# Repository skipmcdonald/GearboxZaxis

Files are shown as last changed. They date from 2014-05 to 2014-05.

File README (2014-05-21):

This is a test project for a mechanical z-axis for the Shapoko 2 to move the motor out of the way and provide better clearance for large spindles such as the Dewalt 611.

The power of OpenScad is shown in the easy to understand source files.

It uses herringbone gears to reduce/eliminate backlash caused by traditional gear meshing tolerances 

The idler gear is intended to have 2 sandwiched 608 bearings and an 8mm hub.  5/16 works in a pinch.   

The lead screw gear is intended to be used with the stock Shapeoko flanged bearing that came in the kit.  Optionally a second bearing (standard 608) can sandwich the gear and held down with to top_br_zplate to add stability.

The gears are designed to be printed on a well-tuned 3d printer. 
The plates are designed to be machined out of aluminum using the Shapeoko 2.
They will be printed for a fitting prototype to ensure all dimensions and tolerances.
The zplate will be machined first. 
The other plates may remain plastic since they don't need to be that strong.

Parts List.
Basic plate hardware:
1 ZPLATE (make using dxf export from makerslide_plate.scad)
1 BR_ZPLATE ( make using dxf or stl export from makerslide_plate.scad )
2 M3 x 15mm  (retention plate fasteners)
2 M3 Nyloc Nuts
4 M3 washers
1 608 flanged bearing (from Shapeoko 2 kit)
1 M8 lead screw (from kit or longer to give additional down travel if needed)
2 M8 washers (get extras to use as optional spacers on lead screw)
3 M8 Nuts (1 below bearing 1 on top and one inserted into lead screw gear.

Stepper Motor hardware:
1 - Nema 17 stepper motor ( from kit)
2 M3 x 10mm (Nema17 z-motor mount)
2 M3 washers (optional)
1 gear (Nema17_motor_gear from gearbox.scad)
1 M3 hex nut (inserted into slot on gear)
1 M3 grub screw (secured through the gear and nut into the motor shaft flat

Gearbox
1 IDLER_GEAR (stl from gearbox.scad)
2 608ZZ sealed Skateboard bearings
1 M8 x 30mm bolt (37mm threaded rod and another nut could work instead)
1 M8 nut
1 M8 Nyloc nut
1 M8 Washer (spacer - can use extras for addition spacing as needed)

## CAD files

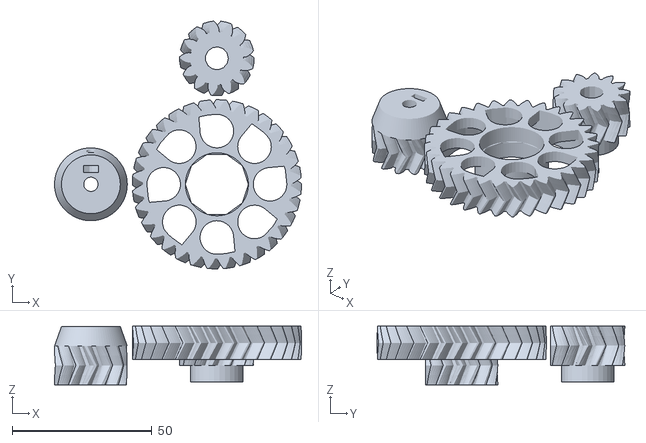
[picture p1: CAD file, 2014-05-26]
gearbox.stl
88.2 x 88.5 x 21.0

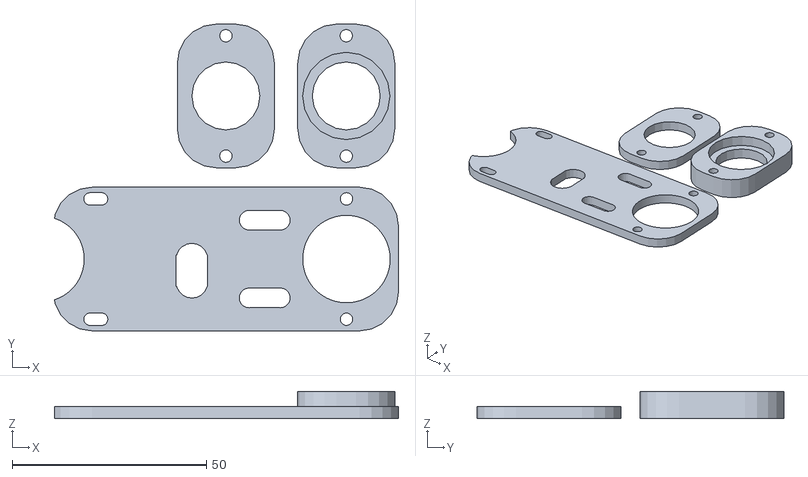
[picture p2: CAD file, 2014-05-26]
makerslide_plate.stl
88.6 x 79.0 x 7.00

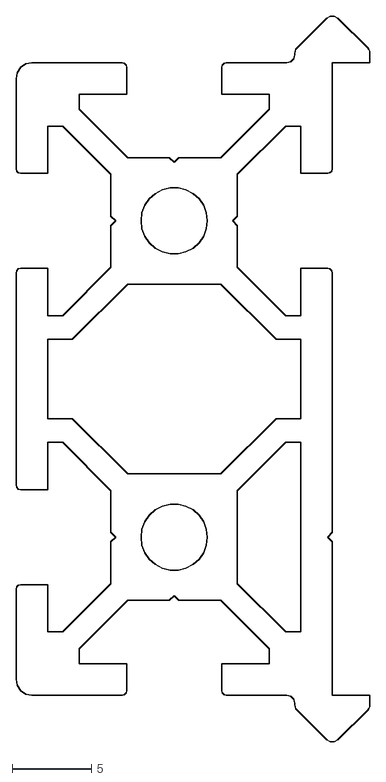
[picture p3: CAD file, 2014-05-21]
makerslide_extrusion_profile.dxf
22.4 x 45.9

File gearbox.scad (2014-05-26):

/* Gear set for Shapeoko to invert the z-axis motor and provied more clearance
 * This use 2 modules from the MCAD library that you can
 *  get from https://github.com/elmom/MCAD.
 * 
 *
 * Based roughly on extruder gear set for TechZone Huxley Copyright (C) 2011 by
 *  Guy 'DeuxVis' P. (thanks DeuxVis) which is derrived from
 *  http://www.thingiverse.com/thing:3104
 *  (thanks GilesBathgate) which is under GPL CC license.
 *
 * This program is free software; you can redistribute it and/or
 * modify it under the terms of the GNU General Public License
 * as published by the Free Software Foundation; either version 2
 * of the License, or (at your option) any later version.
 * 
 * This program is distributed in the hope that it will be useful,
 * but WITHOUT ANY WARRANTY; without even the implied warranty of
 * MERCHANTABILITY or FITNESS FOR A PARTICULAR PURPOSE.  See the
 * GNU General Public License for more details.

 * You should have received a copy of the GNU General Public License
 * along with this program; if not, write to the Free Software Foundation, 
 * Inc., 51 Franklin Street, Fifth Floor, Boston, MA  02110-1301, USA.
 */ 
 // Go to the bottom of this file and remove selected comments to get parts you can print.
// flip stl exported part over before printing and print each part separately for best results.

include <MCAD/teardrop.scad>
include <MCAD/involute_gears.scad>

/* Herringbone gear module, adapted from MCAD/involute_gears */
module herringbone_gear( teeth=12, circles=0, shaft=5, height=14 ) {
  twist=200;
//  height=14;
  pressure_angle=30;

  gear(
    number_of_teeth=teeth,
    circular_pitch=320,
		pressure_angle=pressure_angle,
		clearance = 0.2,
		gear_thickness = height/2,
		rim_thickness = height/2,
		rim_width = 1,
		hub_thickness = height/2,
		hub_diameter=1,
		bore_diameter=shaft,
		circles=circles,
		twist=twist/teeth
  );

	mirror( [0,0,1] )
	  gear(
      number_of_teeth=teeth,
		  circular_pitch=320,
		  pressure_angle=pressure_angle,
		  clearance = 0.2,
		  gear_thickness = height/2,
		  rim_thickness = height/2,
		  rim_width = 1,
		  hub_thickness = height/2,
		  hub_diameter=1,
		  bore_diameter=shaft,
		  circles=circles,
		  twist=twist/teeth
    );
}
// Idler Gear
module idler_gear(){
tears = 8; 
  union() {
    //gear
    herringbone_gear( teeth=32, circles=0, shaft=25*2, height=12 );
	 translate([0,0,12/2-4/2]) difference() {
				cylinder(r=25.1, h=4,center = true);
				cylinder(r=22.5/2, h=4.1,center = true, $fn = 100);

		//teardrop shaped holes 
  				for(i=[0:tears-1])
   				 rotate( [0, 0, i*360/tears] )
    				  translate( [19, 0, 0] )
    				    rotate( [0, 90, 50] ) teardrop( 6, 11, 90 );

				}
	difference(){
	 translate([0,0,0]) cylinder(r=(22.5+3)/2, h=12,center = true, $fn = 100);
    translate([0,0,0]) cylinder(r=22.5/2, h=12.1,center = true,$fn = 100);
	 }
    //608 bearing trap
    difference() {
      translate( [0, 0, 0] ) cylinder( r=12, h=.5, center = true );
      translate( [0, 0, 0] ) cylinder( r=11.25, h=10, $fn=10, center = true );
    	}
    }
// shaft position
% cylinder (r=4, h = 60, center = true);
// bearing positions
% translate([0,0,-3.7])cylinder (r=22/2, h = 7, center = true);
% translate([0,0, 3.7])cylinder (r=22/2, h = 7, center = true);
// Nut clearance
% translate( [0, 0, -14] ) cylinder( r=6.6, h=7, $fn=6 );
% translate( [0, 0, -30] ) cylinder( r=6.6, h=7, $fn=6 );
// radius mesh
% cylinder (r=28.44444, h=1);

}

// Leadscrew Gear
module leadscrew_gear(){
difference() {
  union() {
    //gear
    herringbone_gear( teeth=13, circles=0, shaft=8.2 );

    //M8 bolt head fit washer
    difference() {
      translate( [0, 0, -13] ) cylinder( r=9.4, h=6 );
      translate( [0, 0, -13.5] ) cylinder( r=7.7, h=7, $fn=6 );
    }
  }
}
// shaft position
% cylinder (r=4, h = 60, center = true);
// radius mesh
% cylinder (r=11.5556, h=1);
// Nut clearance
% translate( [0, 0, -14] ) cylinder( r=6.6, h=7, $fn=6 );
% translate( [0, 0, 7] ) cylinder( r=6.6, h=7, $fn=6 );
}
 
// Motor gear
module Nema17_motor_gear(){
 union() difference() {	 
  union() {

    //gear
    herringbone_gear( teeth=13 );

    translate( [0, 0, 13.9] ) mirror( [0, 0, 1] ) difference() {
      union() {

        //base
			cylinder(h=7, r1=10.5, r2=13.0, $fn = 80);


        //shaft
 //%       cylinder( r=5, h=18 );
      }

      //captive nut and grub holes
      translate( [0, 20, 4] ) rotate( [90, 0, 0] ) union() {
        //enterance
        translate( [0, -3, 14.5] ) cube( [5.4, 6, 2.4], center=true );
        //nut
        translate( [0, 0, 13.3] ) rotate( [0, 0, 30] ) cylinder( r=3.14, h=2.4, $fn=6 );
        //grub hole
        translate( [0, 0, 5] ) cylinder( r=1.6, h=15 );
      }
    }
  }

  //shaft hole
  translate( [0, 0, 0] ) cylinder( r=2.55, h=35, center = true );
 }
// Nema 17 specs
	case = 42.3;
	holes17=31;
	collar_d = 22.05;
	collar_h = 2;
	shaft_l = 24;
	shaft_d = 5.3;
	m3 = 3.1;
	$fn = 30;
// show nema17 outline for positioning
	% cylinder (r=shaft_d/2, h=shaft_l);
	% translate([0,0, 24]) cylinder(r = collar_d/2, h = collar_h);
	% translate([holes17/2,holes17/2, 22])cylinder(r=m3/2, h = 9);
	% translate([-holes17/2,holes17/2, 22])cylinder(r=m3/2, h = 9);
	% translate([holes17/2,-holes17/2, 22])cylinder(r=m3/2, h = 9);
	% translate([-holes17/2,-holes17/2, 22])cylinder(r=m3/2, h = 9);
   % translate([0,0, 26]) cube([case,case,1], center = true);
// radius mesh
% cylinder (r=11.5556, h=1);
}

// Assembly  -maximum separation center to center of 80
module gearbox(){
rotate([0,180,0])translate( [0, 0, 0] )idler_gear();
translate( [40, 0, 0] )leadscrew_gear();
translate( [-40, 0, 0] ) Nema17_motor_gear();
}

//gearbox();  // for test fit only do not export
idler_gear();  // for stl export
translate( [0, 45, -1] ) leadscrew_gear(); // for stl export
translate( [-45, 0, -8] )Nema17_motor_gear(); // for stl export

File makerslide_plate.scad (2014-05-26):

// flip it over for viewing in the correct orientation.
// Skip McDonald copyright 2014 - GNU license use it and abuse it but give me some credit.
// Warning this desing is somewhat incomplete as of 21May2014 you have been warned.



include <gearbox.scad>

//new plate dimensions
in = 25.4;
cx = 3.5*in;
//cy = 1.5*in;
cy =37;
cz = 1/8*in;
screw3 = 3.2;
screw5 = 5.1;
screw8 = 8.1;
leadscrew = 8.5;
bearing_d = 22.50;
bearing_h = 7;
//original plate dimensions
ox = 57.15;
oy = 50.80;
oz = 6.35;
screw = 5;
rad = 10; //corner radius size

module makerslide(h=100) {
	linear_extrude(file="makerslide_extrusion_profile.dxf", layer="makerslide",height=h, center=true, convexity=10);
}

% translate([0,0,50+cz/2])makerslide();
$fn=20;
//Clearance for screw head and washer
% translate([10,10,0])cylinder(h=12, r=5/2, center = true);
% translate([10,-10,0])cylinder(h=12, r=5/2, center = true);

module zplate(){   // alumium underplate for strength -- pla for fitting prototype only
// center marker
% cylinder(h=30, r=.5); // just a guide mark doesn't effect part

// Plate Base
	difference(){
	cube([cx,cy,cz], center = true);
// Makerslide holes

	translate([6,10,0])cylinder(h=20, r=screw5/2, center = true);
	translate([6,-10,0])cylinder(h=20, r=screw5/2, center = true);
	translate([14,10,0])cylinder(h=20, r=screw5/2, center = true);
	translate([14,-10,0])cylinder(h=20, r=screw5/2, center = true);
	translate([10,-10,0])cube([8,screw,20],center = true);
	translate([10,10,0])cube([8,screw,20],center = true);
// idler gear 
// hole 0.25mm too close to leadscrew gear on purpose in
// case of gear print tolerance, length of hole allows proper tensioning
	translate([-8.75,0,0])cylinder(h=20, r=screw8/2, center = true);
	translate([-8.75,-6,0])cylinder(h=20, r=screw8/2, center = true);
	translate([-8.75,-3,0])cube([screw8,screw8,20],center = true);
// Nema17 holes
	translate([-47.5,0,0])cylinder(h=20, r=22/2, center = true, $fn = 100);
	translate([-47.5+15.5,-15.5,0])cylinder(h=20, r=screw3/2, center = true);
	translate([-47.5+15.5,15.5,0])cylinder(h=20, r=screw3/2, center = true);
	translate([-49+15.5,-15.5,0])cube([3,screw3,20], center = true);
	translate([-49+15.5,15.5,0])cube([3,screw3,20], center = true);
	translate([-50.5+15.5,-15.5,0])cylinder(h=20, r=screw3/2, center = true);
	translate([-50.5+15.5,15.5,0])cylinder(h=20, r=screw3/2, center = true);





// radius the corners
	difference(){
		translate([(cx-rad)/2,(cy-rad)/2,0]) cube([rad,rad,20],center = true);		
		translate([cx/2-rad,(cy)/2-rad,0]) cylinder(h=20, r=rad, center = true);
		}
	difference(){
		translate([(-cx+rad)/2,(cy-rad)/2,0]) cube([rad,rad,20],center = true);		
		translate([-cx/2+rad,(cy)/2-rad,0]) cylinder(h=20, r=rad, center = true);
		}
	difference(){
		translate([(-cx+rad)/2,(-cy+rad)/2,0]) cube([rad,rad,20],center = true);	
		translate([-cx/2+rad,(-cy)/2+rad,0]) cylinder(h=20, r=rad, center = true);
		}
	difference(){
		translate([(cx-rad)/2,(-cy+rad)/2,0]) cube([rad,rad,20],center = true);		
		translate([cx/2-rad,(-cy)/2+rad,0]) cylinder(h=20, r=rad, center = true);
		}

// Bearing hole
  translate([31.05,0,0])cylinder(h=15,r=bearing_d/2, center = true,$fn=100);

// Bearing retention holes
	translate([31.05,-15.5,0])cylinder(h=15,r=screw3/2, center = true);
	translate([31.05,15.5,0])cylinder(h=15,r=screw3/2, center = true);

	}

}
bx = 25;
module br_zplate(){   // bearing retention plate
// center marker
% cylinder(h=30, r=.5); // just a guide mark doesn't effect part

// Plate Base
	difference(){
		cube([bx,cy,cz], center = true);
// radius corners
	difference(){
		translate([(bx-rad)/2,(cy-rad)/2,0]) cube([rad,rad,20],center = true);		
		translate([bx/2-rad,(cy)/2-rad,0]) cylinder(h=20, r=rad, center = true);
		}
	difference(){
		translate([(-bx+rad)/2,(cy-rad)/2,0]) cube([rad,rad,20],center = true);		
		translate([-bx/2+rad,(cy)/2-rad,0]) cylinder(h=20, r=rad, center = true);
		}
	difference(){
		translate([(-bx+rad)/2,(-cy+rad)/2,0]) cube([rad,rad,20],center = true);	
		translate([-bx/2+rad,(-cy)/2+rad,0]) cylinder(h=20, r=rad, center = true);
		}
	difference(){
		translate([(bx-rad)/2,(-cy+rad)/2,0]) cube([rad,rad,20],center = true);		
		translate([bx/2-rad,(-cy)/2+rad,0]) cylinder(h=20, r=rad, center = true);
		}
// zplate mating holes
	translate([0,-15.5,0])cylinder(h=15,r=screw3/2, center = true);
	translate([0,15.5,0])cylinder(h=15,r=screw3/2, center = true);

// bearing access hole
	cylinder(h=15,r=(bearing_d-5)/2, center = true);
	}
}

bz = 7;
module br_top_zplate(){   // optional top bearing -- retention plate
// center marker -- reminds me where center is if I rotate the part
% cylinder(h=30, r=.5); // just a guide mark doesn't effect part

// Plate Base
	difference(){
		cube([bx,cy,bz], center = true);
// radius corners
	difference(){
		translate([(bx-rad)/2,(cy-rad)/2,0]) cube([rad,rad,20],center = true);		
		translate([bx/2-rad,(cy)/2-rad,0]) cylinder(h=20, r=rad, center = true);
		}
	difference(){
		translate([(-bx+rad)/2,(cy-rad)/2,0]) cube([rad,rad,20],center = true);		
		translate([-bx/2+rad,(cy)/2-rad,0]) cylinder(h=20, r=rad, center = true);
		}
	difference(){
		translate([(-bx+rad)/2,(-cy+rad)/2,0]) cube([rad,rad,20],center = true);	
		translate([-bx/2+rad,(-cy)/2+rad,0]) cylinder(h=20, r=rad, center = true);
		}
	difference(){
		translate([(bx-rad)/2,(-cy+rad)/2,0]) cube([rad,rad,20],center = true);		
		translate([bx/2-rad,(-cy)/2+rad,0]) cylinder(h=20, r=rad, center = true);
		}
// zplate mating holes
	translate([0,-15.5,0])cylinder(h=15,r=screw3/2, center = true);
	translate([0,15.5,0])cylinder(h=15,r=screw3/2, center = true);

// bearing access hole
	cylinder(h=15,r=(bearing_d-5)/2, center = true);

// bearing seat recess
	translate ([0,0,bz/2])cylinder(h=7,r=(bearing_d)/2, center = true);
	}
// image of 608 bearing for fitting purposes
%	difference(){
		translate ([0,0,bz/2])cylinder(h=7,r=(bearing_d)/2, center = true, $fn=200);
		translate ([0,0,bz/2])cylinder(h=15,r=screw8/2, center = true);
   }
}

/*	
module original_z_plate(){

	
translate([0,0,0])difference(){
	translate([0,0,0.01])cube([ox,oy,oz] );
//Makerslide holes
	translate([44.45,35.4,0])cylinder(h=20, r=screw/2);
	translate([44.45,15.40,0])cylinder(h=20, r=screw/2);
	translate([52.45,35.4,0])cylinder(h=20, r=screw/2);
	translate([52.45,15.40,0])cylinder(h=20, r=screw/2);
	translate([44.45,35.4-screw/2,0])cube([8,screw,20]);
	translate([44.45,15.40-screw/2,0])cube([8,screw,20]);
//Motor Nema17 holes
	translate([28.10,3.49,0])cylinder(h=20, r=3.2/2);
	translate([28.10,47.32,0])cylinder(h=20, r=3.2/2);
	translate([6.19,25.40,0])cylinder(h=20, r=3.2/2);
//Bearing hole
	translate([28.10,25.40,0])cylinder(h=20, r=bearing_d/2);

%  translate([28.10,25.40,0])cylinder(h=20, r=leadscrew/2);
%  translate([28.10,25.40,0])cylinder(h=20, r=0.1, center = true);
//Radius corners
	difference(){
		translate([0,0,0]) cube([rad,rad,20]);		
		translate([rad,rad,0]) cylinder(h=20, r=rad);
	}
	difference(){
		translate([ox-rad,0,0]) cube([rad,rad,20]);		
		translate([ox-rad,rad,0]) cylinder(h=20, r=rad);
	}
	difference(){
		translate([ox-rad,oy-rad,0]) cube([rad,rad,20]);		
		translate([ox-rad,oy-rad,0]) cylinder(h=20, r=rad);
	}
	difference(){
		translate([0,oy-rad,0]) cube([rad,rad,20]);		
		translate([rad,oy-rad,0]) cylinder(h=20, r=rad);
	}

	}
}
*/

//%rotate([0,180,0])translate([-ox-2,-oy/2,0])original_z_plate();
// zplate();  // for stl export
//%translate ([31,0,-cz])br_zplate();  //  display
//%translate ([31,0,-38])br_top_zplate(); // display
//% translate([-9,0,-17])gearbox();  // display purposes only


//projection(cut = true) zplate();  // for dxf export
//projection(cut = true) br_zplate();  // for dxf export

// prototype print the parts.
translate ([0,0,cz/2])zplate();  // for stl export
translate ([0,cy+5,cz/2])br_zplate();  // for stl export
translate ([31,cy+5,bz/2])br_top_zplate(); // for stl export

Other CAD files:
makerslide_plate.dxf

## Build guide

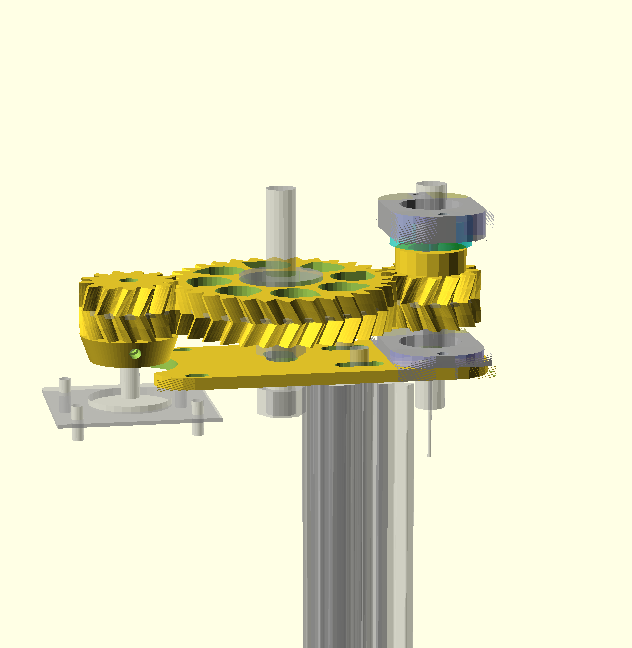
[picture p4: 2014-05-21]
assembly.png

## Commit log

2014-05-21 Initial check in, ready for testing, still need to add bearing clip or retention method
    [gearbox.scad, gearbox.stl, makerslide_extrusion_profile.dxf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]
2014-05-21 Added retention plates to original design.
    [makerslide_plate.scad, makerslide_plate.stl]
2014-05-21 Picture of the gearbox assembly added
2014-05-26 Adjustments made after initial fitting.
    [gearbox.scad, makerslide_plate.scad]
2014-05-26 fixed bearing size for 608zz and 8mm nut size
    [gearbox.stl, makerslide_plate.stl]
